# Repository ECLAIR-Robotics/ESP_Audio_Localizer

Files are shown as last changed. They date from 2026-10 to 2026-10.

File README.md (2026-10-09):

# Audio Localization
## The Basics
## The Math
# Build Guide
## Hardware
### Parts to Buy:
- ESP32 (-S3 Preferred)
- Electret Microphone
- Wiring
- M3x18 Screws
- M3 Nuts
- 3mm Magnets
### Parts to Print
- Left Body x1
- Right Body x1
- ESP Mount x1
- Mic Holder x4
## Microcontroller Code
### Structure
### Notable Constants
## Tuning the Constants
## Output
### Visualizer
### Other

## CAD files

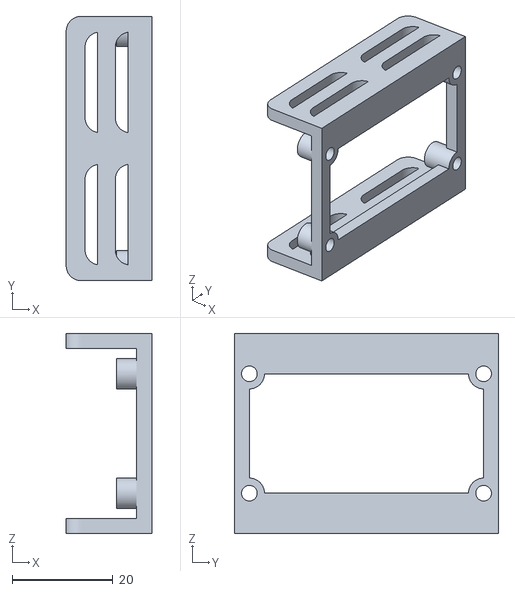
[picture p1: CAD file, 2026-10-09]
Hardware/ESP_Mount.stl
17.0 x 52.5 x 39.7

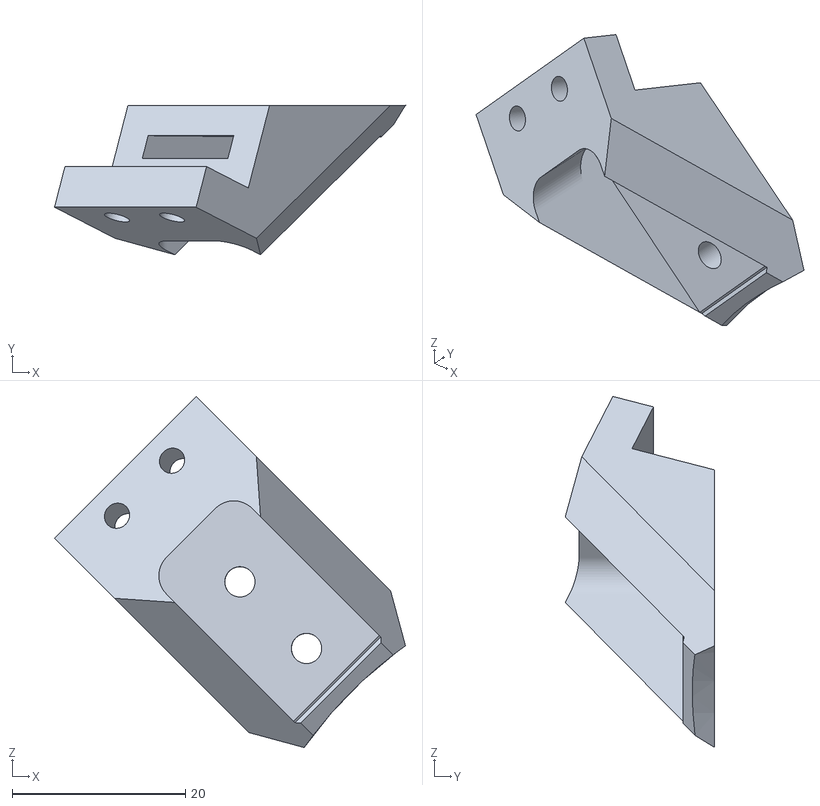
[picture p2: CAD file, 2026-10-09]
Hardware/Mic_Holder.stl
40.6 x 17.3 x 40.6

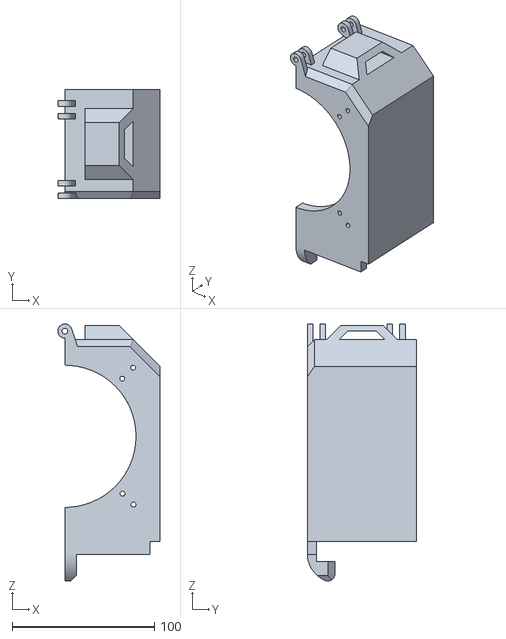
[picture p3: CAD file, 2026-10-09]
Hardware/Right_Body.stl
72.0 x 77.0 x 180.8

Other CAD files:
Hardware/Left_Body.stl

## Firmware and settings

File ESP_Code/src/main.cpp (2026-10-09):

#include <Arduino.h>
#include <WiFi.h>
#include "driver/adc.h"
#include "driver/i2s.h"
#include "soc/syscon_reg.h"
#include "soc/syscon_struct.h"
#include "soc/sens_reg.h"
#include "soc/sens_struct.h"
#include "LinAlg.h"

// ── Mode selection ────────────────────────────────────────────────────────────
// MODE_TEST      → outputs "v0,v1,v2,v3\n" (raw ADC counts) for mic_calibration.py
// MODE_PRODUCTION → outputs "az_degrees\n" (0–360) for visualizer.py
#define MODE_PRODUCTION 0
#define MODE_TEST       1
#define MODE_ROS        2
#define MODE            MODE_PRODUCTION

#define CROWDED_AREA    1   // 1 = periodic background xcorr subtraction for noisy environments

// ── Tunable constants ─────────────────────────────────────────────────────────
// SAMPLES: recording window = SAMPLES / (I2S_SAMPLE_RATE/4) ms. Trade-off:
//   fewer → shorter window, less multi-speaker bleed, noisier xcorr
//   more  → better voice SNR, higher risk of capturing a second speaker mid-window
// Multi-speaker rule of thumb: keep window ≤ 15 ms (SAMPLES ≤ 300).
// Single-speaker / music: SAMPLES = 500–600 improves voice accuracy noticeably.
static constexpr int    SAMPLES         = 300;
// I2S streams all 4 channels interleaved at I2S_SAMPLE_RATE total.
// Each mic gets I2S_SAMPLE_RATE/4 = 20 kHz → 50 µs per mic-sample.
static constexpr int    I2S_SAMPLE_RATE = 80000;
static constexpr int    I2S_DMA_BUF_LEN = 256;
static constexpr int    I2S_DMA_BUF_CNT = 4;

// XCORR_RANGE: at 20 kHz/mic (80 kHz total), max TDOA across 17.7 cm diagonal ≈ 10.3 samples. Use 12.
static constexpr int    XCORR_RANGE     = 12;

// VOLTAGE: per-mic 12-bit ADC count at idle. Calibrate with MODE_TEST first.
static constexpr int    VOLTAGE[4]      = {1919, 1913, 1915, 1925};

// THRESHOLD: single-sample abs deviation that fires the recording trigger.
static constexpr int           THRESHOLD    = 50; //400
// COOLDOWN_MS: silence window after each recording — suppresses echo re-triggers.
static constexpr unsigned long COOLDOWN_MS  = 200;
#if CROWDED_AREA
// BG_UPDATE_MS: how often to re-sample the ambient background (during silence).
static constexpr unsigned long BG_UPDATE_MS = 2000;
// BG_ALPHA: EMA weight applied to each new background estimate (0=never update, 1=instant replace).
static constexpr float         BG_ALPHA     = 0.5f;
// CALIBRATION_MS: silent window used to measure ambient noise and set dynamic threshold
// (run once at startup, then re-run periodically — see RECALIBRATION_MS).
static constexpr unsigned long CALIBRATION_MS = 2000;
// CAL_SIGMA_MULT: how many std-devs above the noise mean a sample must deviate to trigger.
// Lower = more sensitive (more false triggers from noise); higher = less sensitive (misses quieter sounds).
static constexpr float         CAL_SIGMA_MULT  = 1.5f;
// CAL_FLOOR_MARGIN: minimum trigger margin above the noise mean, even if std_dev is ~0.
static constexpr int           CAL_FLOOR_MARGIN = 100;
// RECALIBRATION_MS: how often to re-run calibration after the previous one finishes,
// so the noise floor tracks a changing crowd/environment.
static constexpr unsigned long RECALIBRATION_MS = 5UL * 60 * 1000;
#endif

static constexpr double SPEED_SOUND     = 343.0;
static constexpr bool   INCL_EDGE       = false;
// NCC_THRESHOLD: minimum normalized cross-correlation peak to accept a TDOA estimate.
// Raise if random-direction readings persist; lower if real sounds are being rejected.
static constexpr float  NCC_THRESHOLD   = 0.25f;

// CH_SKEW_US: within-cycle sampling delay per channel (12.5 µs/slot at 80 kHz).
// Scan order CH0→CH3→CH6→CH7 means mic1 is sampled 12.5 µs after mic0, etc.
static constexpr double CH_SKEW_US[4]  = {0.0, 12.5, 25.0, 37.5};

// ── ADC wiring ────────────────────────────────────────────────────────────────
// GPIO 36 (VP) = ADC1_CH0  → MIC 0
// GPIO 39 (VN) = ADC1_CH3  → MIC 1
// GPIO 34      = ADC1_CH6  → MIC 2
// GPIO 35      = ADC1_CH7  → MIC 3
static const adc1_channel_t MIC_CH[4] = {
    ADC1_CHANNEL_0, ADC1_CHANNEL_3, ADC1_CHANNEL_6, ADC1_CHANNEL_7,
};
// Reverse lookup: ADC1 channel index (0–7) → mic index, -1 = unused
static const int CH_TO_MIC[8] = {0, -1, -1, 1, -1, -1, 2, 3};

// ── Microphone geometry (meters, 12.5 cm square) ─────────────────────────────
static const Vector MIC_LOC[4] = {
    { 0.0625, -0.0625, 0},
    { 0.0625,  0.0625, 0},
    {-0.0625,  0.0625, 0},
    {-0.0625, -0.0625, 0},
};
static const int MIC_PAIRS[6][2] = {{0,1},{0,2},{0,3},{1,2},{1,3},{2,3}};

// ── Sample buffers ────────────────────────────────────────────────────────────
static int          reads[4][SAMPLES];
static unsigned int ts[4][SAMPLES];       // pre-filled uniform 100 µs spacing
static int          fill[4]    = {0};
static bool         recording     = false;
static bool         align_to_ch0  = false;
static uint16_t     dma_buf[I2S_DMA_BUF_LEN];

// ── Internal types ────────────────────────────────────────────────────────────
struct AnnotatedVec {
    Vector v; bool edge;
    AnnotatedVec() : v(), edge(true) {}
    AnnotatedVec(Vector _v, bool _e) : v(_v), edge(_e) {}
};
struct Cone {
    Vector n; double s;
    Cone() : n(), s(0) {}
    Cone(Vector _n, double _s) : n(_n), s(_s) {}
};
static Cone cones[6];

#if CROWDED_AREA
static float         bg_xcorr[6][2 * XCORR_RANGE + 1]; // per-pair background xcorr (float for EMA)
static bool          bg_valid        = false;
static int           bg_buf[4][SAMPLES];
static bool          bg_capturing    = false;
static bool          bg_align_to_ch0 = false;
static int           bg_fill[4]      = {0};
static unsigned long last_bg_ms      = 0;
static bool          calibrating      = true;
static long long     cal_sum          = 0;
static long long     cal_sum2         = 0;   // sum of squares for 3-sigma threshold
static long          cal_count        = 0;
static int           dynamic_threshold = THRESHOLD;
static unsigned long calibration_start_ms = 0;
static unsigned long last_calibration_end_ms = 0; // used to schedule the next recalibration
#endif

// ── Cross-correlation TDOA ────────────────────────────────────────────────────
// Returns time offset in seconds. Negative = a received the signal first.
static double xcorr_tdoa(const int* a, const unsigned int* a_ts, int va,
                          const int* b, const unsigned int* b_ts, int vb,
                          const float* bg_sub = nullptr) {
    double time_step = 1e-6 * (((long)a_ts[SAMPLES-1] - a_ts[0]) +
                                ((long)b_ts[SAMPLES-1] - b_ts[0])) / (2.0 * (SAMPLES - 1));

    static long xcorr[2 * XCORR_RANGE + 1];
    for (int lag = -XCORR_RANGE; lag <= XCORR_RANGE; lag++) {
        long corr = 0;
        int  lo2  = (lag >= 0) ? lag + 1 : 1;   // keeps a[i-1] and b[i-lag-1] in bounds
        int  hi2  = (lag >= 0) ? SAMPLES : SAMPLES + lag;
        for (int i = lo2; i < hi2; i++)
            corr += (int32_t)(a[i] - a[i-1]) * (int32_t)(b[i-lag] - b[i-lag-1]);
        xcorr[lag + XCORR_RANGE] = corr;
    }

    // Optionally subtract background xcorr (CROWDED_AREA); convert to float for peak detection.
    float xcorr_f[2 * XCORR_RANGE + 1];
    for (int i = 0; i <= 2 * XCORR_RANGE; i++)
        xcorr_f[i] = bg_sub ? (float)xcorr[i] - bg_sub[i] : (float)xcorr[i];

    int pk = 0;
    for (int i = 1; i <= 2 * XCORR_RANGE; i++)
        if (xcorr_f[i] > xcorr_f[pk]) pk = i;

    // NCC quality gate: peak must be large relative to both signal energies.
    // Filters noisy-but-positive peaks that give wrong TDOA on low-SNR recordings.
    {
        float ea = 0.0f, eb = 0.0f;
        for (int i = 1; i < SAMPLES; i++) {
            float da = (float)(a[i] - a[i-1]), db = (float)(b[i] - b[i-1]);
            ea += da*da; eb += db*db;
        }
        if (ea < 1.0f || eb < 1.0f ||
            xcorr_f[pk] / (sqrtf(ea) * sqrtf(eb)) < NCC_THRESHOLD)
            return NAN;
    }

    double interp = pk;
    if (pk > 0 && pk < 2 * XCORR_RANGE) {
        double fa = xcorr_f[pk-1], fb = xcorr_f[pk], fc = xcorr_f[pk+1];
        double denom = fa - 2.0*fb + fc;
        if (fabs(denom) > 1.0)
            interp = pk + 0.5*(fa - fc) / denom;
    }

    return time_step * (interp - XCORR_RANGE);
}

#if CROWDED_AREA
// Computes first-diff xcorr for all 6 pairs from bg_buf[] and EMA-blends into bg_xcorr[].
static void update_bg_xcorr() {
    for (int pi = 0; pi < 6; pi++) {
        const int a = MIC_PAIRS[pi][0], b = MIC_PAIRS[pi][1];
        for (int lag = -XCORR_RANGE; lag <= XCORR_RANGE; lag++) {
            long corr = 0;
            const int lo2 = (lag >= 0) ? lag + 1 : 1;
            const int hi2 = (lag >= 0) ? SAMPLES : SAMPLES + lag;
            for (int i = lo2; i < hi2; i++)
                corr += (int32_t)(bg_buf[a][i] - bg_buf[a][i-1])
                      * (int32_t)(bg_buf[b][i-lag] - bg_buf[b][i-lag-1]);
            const int idx = lag + XCORR_RANGE;
            bg_xcorr[pi][idx] = bg_valid
                ? BG_ALPHA * (float)corr + (1.0f - BG_ALPHA) * bg_xcorr[pi][idx]
                : (float)corr;
        }
    }
    bg_valid     = true;
    last_bg_ms   = millis();
    bg_capturing = false;
    Serial.println("bg");   // diagnostic: remove once verified
}
#endif

// ── Cone geometry ─────────────────────────────────────────────────────────────
static inline int sign_of(double x) { return (x > 0) - (x < 0); }

// Returns the tangent of the cone's half-angle (slope = adjacent/opposite).
// Returns 0 if dt is effectively zero (source equidistant → skip this pair).
static double cone_slope(double dt, double dist) {
    if (fabs(dt) < 1e-9) return 0.0;   // guard: avoids sqrt(dist²)/0
    double ct = SPEED_SOUND * fabs(dt);
    return (dist <= ct) ? 0.0 : sqrt(dist*dist - ct*ct) / ct;
}

static AnnotatedVec cone_intersect(const Cone& c1, const Cone& c2) {
    double alpha = atan(c1.s);
    double beta  = atan(c2.s);
    double theta = acos(fmax(-1.0, fmin(1.0, dot(c1.n, c2.n))));
    Vector ax    = normalize(cross(c2.n, c1.n));
    double z     = cos(alpha);
    double bz1   = cos(theta - beta);
    double bz2   = cos(theta + beta);

    if ((bz1 > z) == (bz2 > z)) {
        double diffs[4] = {
            fabs((theta-beta) - alpha), fabs((theta+beta) - alpha),
            fabs((theta-beta) + alpha), fabs((theta+beta) + alpha),
        };
        int mi = 0;
        for (int i = 1; i < 4; i++) if (diffs[i] < diffs[mi]) mi = i;
        double ang = (mi == 0) ?  beta + ((theta-beta)-alpha)/2.0
                   : (mi == 1) ? -beta + ((theta+beta)-alpha)/2.0
                   : (mi == 2) ?  beta + ((theta-beta)+alpha)/2.0
                   :             -beta + ((theta+beta)+alpha)/2.0;
        return AnnotatedVec(matrix_multiplication(rotaion_matrix_around_axis(ax, -ang), c2.n), true);
    }

    Vector w     = Vector(0, sin(theta - beta), cos(theta - beta));
    Vector nv    = Vector(0, sin(theta),        cos(theta));
    double denom = w.z - w.y*nv.y*nv.z - nv.z*nv.z*w.z;
    if (fabs(denom) < 1e-9) return AnnotatedVec();
    double ang   = acos(fmax(-1.0, fmin(1.0, (z - w.y*nv.y*nv.z - nv.z*nv.z*w.z) / denom)));
    Vector base  = matrix_multiplication(rotaion_matrix_around_axis(ax, beta), c2.n);
    Vector d1    = matrix_multiplication(rotaion_matrix_around_axis(c2.n,  ang), base);
    Vector d2    = matrix_multiplication(rotaion_matrix_around_axis(c2.n, -ang), base);
    return AnnotatedVec(d1.z > 0 ? d1 : d2, false);
}

static Vector sound_direction() {
    for (int i = 0; i < 6; i++) {
        int a = MIC_PAIRS[i][0], b = MIC_PAIRS[i][1];
        double dt = xcorr_tdoa(reads[a], ts[a], VOLTAGE[a], reads[b], ts[b], VOLTAGE[b],
#if CROWDED_AREA
                               bg_valid ? bg_xcorr[i] : nullptr
#else
                               nullptr
#endif
                               );
        dt -= (CH_SKEW_US[b] - CH_SKEW_US[a]) * 1e-6;
        if (isnan(dt))                              { cones[i] = Cone(); continue; } // uncorrelated
        if (fabs(dt) < 1e-9)                        { cones[i] = Cone(); continue; } // equidistant
        double dist = magnitude(MIC_LOC[b] - MIC_LOC[a]);
        if (SPEED_SOUND * fabs(dt) >= dist)         { cones[i] = Cone(); continue; } // impossible TDOA
        cones[i] = Cone(normalize(MIC_LOC[b] - MIC_LOC[a]) * sign_of(dt),
                        cone_slope(dt, dist));
    }

    // Sum valid cone normals → guide vector pointing toward the source hemisphere.
    // Each cone normal already points toward the closer mic (= source side), so
    // the sum is a stable, geometry-free reference for resolving the 180° ambiguity.
    Vector guide(0, 0, 0);
    for (int i = 0; i < 6; i++)
        if (magnitude(cones[i].n) > 0.5) guide = guide + cones[i].n;

#if CROWDED_AREA
    {
        int valid = 0;
        for (int i = 0; i < 6; i++)
            if (magnitude(cones[i].n) > 0.5) valid++;
        if (valid < 3) return Vector(0, 0, 0);
    }
#endif

    Vector candidates[13];
    int n = 0;
    for (int i = 0; i < 5; i++) {
        for (int j = i + 1; j < 6; j++) {
            if ((i == 0 && j == 5) || (i == 1 && j == 4)) continue; // co-axial pairs
            if (magnitude(cones[i].n) < 0.5 || magnitude(cones[j].n) < 0.5) continue;
            if (dot(cones[i].n, cones[j].n) > 0.94) continue; // < 20° apart → ill-conditioned
            AnnotatedVec av = cone_intersect(cones[i], cones[j]);
            if (!av.edge || INCL_EDGE) candidates[n++] = av.v;
        }
    }

    if (n == 0) return Vector(0, 0, 1);

    // Single-pass consensus: flip any candidate pointing against the guide, then sum.
    // Faster than the old two-pass and more reliable because the guide is derived
    // directly from which mic received first rather than from the candidates themselves.
    Vector sum(0, 0, 0);
    for (int i = 0; i < n; i++) {
        Vector v = candidates[i];
        if (dot(v, guide) < 0.0) v = v * -1;
        sum = sum + v;
    }

    return normalize(sum);
}

// ── Arduino entry points ──────────────────────────────────────────────────────
void setup() {
    Serial.begin(115200);
    WiFi.mode(WIFI_OFF);

    for (int i = 0; i < 4; i++)
        adc1_config_channel_atten(MIC_CH[i], ADC_ATTEN_DB_11);

    // Pre-fill ts with uniform 100 µs spacing (10 kHz per mic at 40 kHz total)
    const unsigned int PERIOD_US = 4 * 1000000UL / I2S_SAMPLE_RATE; // = 100
    for (int j = 0; j < SAMPLES; j++)
        for (int i = 0; i < 4; i++)
            ts[i][j] = j * PERIOD_US;

    const i2s_config_t i2s_cfg = {
        .mode                 = (i2s_mode_t)(I2S_MODE_MASTER | I2S_MODE_RX | I2S_MODE_ADC_BUILT_IN),
        .sample_rate          = I2S_SAMPLE_RATE,
        .bits_per_sample      = I2S_BITS_PER_SAMPLE_16BIT,
        .channel_format       = I2S_CHANNEL_FMT_ONLY_RIGHT,
        .communication_format = I2S_COMM_FORMAT_I2S_MSB,
        .intr_alloc_flags     = ESP_INTR_FLAG_LEVEL1,
        .dma_buf_count        = I2S_DMA_BUF_CNT,
        .dma_buf_len          = I2S_DMA_BUF_LEN,
        .use_apll             = false,
        .tx_desc_auto_clear   = false,
        .fixed_mclk           = 0,
    };
    i2s_driver_install(I2S_NUM_0, &i2s_cfg, 0, NULL);
    i2s_set_adc_mode(ADC_UNIT_1, MIC_CH[0]);

    // Enable all 4 pads BEFORE i2s_adc_enable
    SENS.sar_meas_start1.sar1_en_pad = (1<<0)|(1<<3)|(1<<6)|(1<<7);

    i2s_adc_enable(I2S_NUM_0);

    // i2s_adc_enable resets PATT_LEN to 0. Overwrite the scan pattern AFTER enable.
    // Entry format: [7:4]=channel, [3:2]=bit_width (3=12-bit), [1:0]=atten (3=11dB)
    SYSCON.saradc_ctrl.sar1_patt_len = 3; // 4 entries (len = count - 1)
    SYSCON.saradc_sar1_patt_tab[0] =
        ((uint32_t)((0<<4)|(3<<2)|3) << 24) |  // CH0 = mic0
        ((uint32_t)((3<<4)|(3<<2)|3) << 16) |  // CH3 = mic1
        ((uint32_t)((6<<4)|(3<<2)|3) <<  8) |  // CH6 = mic2
        ((uint32_t)((7<<4)|(3<<2)|3) <<  0);   // CH7 = mic3
    SYSCON.saradc_ctrl.sar1_patt_p_clear = 1;
    SYSCON.saradc_ctrl.sar1_patt_p_clear = 0;

#if CROWDED_AREA
    calibration_start_ms = millis();
    Serial.println("calibrating...");
#else
    Serial.println("ready");
#endif
}

#if MODE == MODE_TEST
// ── Test loop: outputs "v0,v1,v2,v3\n" per DMA buffer for mic_calibration.py ─
void loop() {
    size_t bytes_read;
    i2s_read(I2S_NUM_0, dma_buf, sizeof(dma_buf), &bytes_read, portMAX_DELAY);
    const int n = (int)(bytes_read / 2);

    int latest[4] = {-1, -1, -1, -1};
    for (int s = 0; s < n; s++) {
        const uint16_t raw = dma_buf[s];
        const int ch = (raw >> 12) & 0xF;
        if (ch > 7) continue;
        const int m = CH_TO_MIC[ch];
        if (m < 0) continue;
        latest[m] = (int)(raw & 0xFFF);
    }
    if (latest[0] < 0 || latest[1] < 0 || latest[2] < 0 || latest[3] < 0) return;
    Serial.printf("%d,%d,%d,%d\n", latest[0], latest[1], latest[2], latest[3]);
}

#else
// ── Production loop: outputs "az_degrees\n" (0–360) for visualizer.py ────────
void loop() {
    static unsigned long last_output_ms = 0;
    size_t bytes_read;
    i2s_read(I2S_NUM_0, dma_buf, sizeof(dma_buf), &bytes_read, portMAX_DELAY);
    const int n = (int)(bytes_read / 2);

    for (int s = 0; s < n; s++) {
        const uint16_t raw = dma_buf[s];
        const int ch = (raw >> 12) & 0xF;
        if (ch > 7) continue;
        const int m = CH_TO_MIC[ch];
        if (m < 0) continue;
        const int val = (int)(raw & 0xFFF);

        if (!recording) {
#if CROWDED_AREA
            if (calibrating) {
                long dev = abs(val - VOLTAGE[m]);
                cal_sum  += dev;
                cal_sum2 += dev * dev;
                cal_count++;
                if (millis() - calibration_start_ms > CALIBRATION_MS) {
                    if (cal_count > 0) {
                        int avg     = (int)(cal_sum / cal_count);
                        float var   = (float)(cal_sum2 / cal_count) - (float)avg * (float)avg;
                        int std_dev = (int)sqrtf(var > 0.0f ? var : 0.0f);
                        dynamic_threshold = avg + (int)(CAL_SIGMA_MULT * std_dev);
                        if (dynamic_threshold < avg + CAL_FLOOR_MARGIN) dynamic_threshold = avg + CAL_FLOOR_MARGIN;
                        Serial.printf("ready: avg=%d std=%d threshold=%d\n", avg, std_dev, dynamic_threshold);
                    } else {
                        dynamic_threshold = THRESHOLD;
                        Serial.printf("ready: threshold=%d\n", dynamic_threshold);
                    }
                    calibrating          = false;
                    last_calibration_end_ms = millis();
                }
            } else {
                const bool trigger = abs(val - VOLTAGE[m]) > dynamic_threshold
                                     && millis() - last_output_ms > COOLDOWN_MS;
                if (trigger) {
                    bg_capturing     = false;
                    recording        = true;
                    align_to_ch0     = true;
                    for (int i = 0; i < 4; i++) fill[i] = 0;
                } else if (bg_capturing) {
                    if (bg_align_to_ch0) {
                        if (m == 0) bg_align_to_ch0 = false; else { continue; }
                    }
                    if (bg_fill[m] < SAMPLES) bg_buf[m][bg_fill[m]++] = val;
                } else if (millis() - last_calibration_end_ms > RECALIBRATION_MS
                           && millis() - last_output_ms > COOLDOWN_MS) {
                    calibrating          = true;
                    calibration_start_ms = millis();
                    cal_sum = cal_sum2 = 0;
                    cal_count            = 0;
                    Serial.println("recalibrating...");
                } else if (millis() - last_bg_ms > BG_UPDATE_MS
                           && millis() - last_output_ms > COOLDOWN_MS) {
                    bg_capturing    = true;
                    bg_align_to_ch0 = true;
                    for (int i = 0; i < 4; i++) bg_fill[i] = 0;
                }
            }
#else
            const bool trigger = abs(val - VOLTAGE[m]) > THRESHOLD
                                 && millis() - last_output_ms > COOLDOWN_MS;
            if (trigger) {
                recording    = true;
                align_to_ch0 = true;
                for (int i = 0; i < 4; i++) fill[i] = 0;
            }
#endif
            continue;
        }

        // Skip samples until the next CH0 so all mics start at the same scan position
        if (align_to_ch0) {
            if (m == 0) align_to_ch0 = false;
            else continue;
        }

        if (fill[m] < SAMPLES)
            reads[m][fill[m]++] = val;
    }

#if CROWDED_AREA
    if (bg_capturing) {
        bool done = true;
        for (int i = 0; i < 4; i++) if (bg_fill[i] < SAMPLES) { done = false; break; }
        if (done) update_bg_xcorr();
    }
#endif

    if (!recording) return;
    for (int i = 0; i < 4; i++) if (fill[i] < SAMPLES) return;

    recording = false;
    last_output_ms = millis();
    Vector dir = sound_direction();
    if (magnitude(dir) < 0.5) return;   // CROWDED_AREA: too few valid cone pairs
#if MODE == MODE_ROS
    Serial.printf("Vector(%.4f,%.4f,%.4f)\n", dir.x, dir.y, dir.z);
#else
    double az  = atan2(dir.y, dir.x) * 180.0 / M_PI;
    if (az < 0.0) az += 360.0;   // convert (-180,180] → [0,360)
    Serial.printf("%.1f\n", az);
#endif
}
#endif

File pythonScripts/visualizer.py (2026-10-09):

"""
Sound localizer visualizer.
Reads angle values (0-360) from the ESP32 over serial and draws a live direction line.

Requirements:
    pip install pyserial matplotlib numpy
"""

import sys
import queue
import threading
from collections import deque

import numpy as np
import matplotlib.pyplot as plt
import matplotlib.animation as animation
import serial
import serial.tools.list_ports

# ── Config ────────────────────────────────────────────────────────────────────
BAUD_RATE   = 115200
PORT        = 'COM3'      # fallback if auto-detect finds nothing
TRAIL_LEN   = 8           # number of ghost lines shown behind the current reading
UPDATE_MS   = 50          # plot refresh interval in milliseconds

DISPLAY_ROTATION_DEG = 90  # rotate the whole compass display clockwise ("to the right")

def rotate_xy(x, y, deg=DISPLAY_ROTATION_DEG):
    """Rotate a cartesian point clockwise by deg."""
    rad = np.radians(deg)
    c, s = np.cos(rad), np.sin(rad)
    return x * c + y * s, -x * s + y * c

def dir_xy(deg, r=1.0):
    """Unit vector (scaled by r) for a compass angle, with display rotation applied."""
    rad = np.radians(deg - DISPLAY_ROTATION_DEG)
    return r * np.cos(rad), r * np.sin(rad)

# Mic positions in metres — must match MIC_LOC order in main.cpp
MIC_POS = np.array([
    [ 0.0625, -0.0625],   # MIC 1  VP  (GPIO 36)
    [ 0.0625,  0.0625],   # MIC 2  VN  (GPIO 39)
    [-0.0625,  0.0625],   # MIC 3      (GPIO 34)
    [-0.0625, -0.0625],   # MIC 4      (GPIO 35)
])
MIC_POS = np.array([rotate_xy(x, y) for x, y in MIC_POS])
MIC_LABELS = ['1 (VP)', '2 (VN)', '3 (34)', '4 (35)']

# ── Serial reader (background thread) ────────────────────────────────────────
angle_queue: queue.Queue = queue.Queue()

def find_port() -> str:
    for p in serial.tools.list_ports.comports():
        if any(k in p.description.upper() for k in ('CP210', 'CH340', 'USB', 'ESP')):
            return p.device
    ports = serial.tools.list_ports.comports()
    return ports[0].device if ports else PORT

def serial_thread(port: str) -> None:
    try:
        ser = serial.Serial(port, BAUD_RATE, timeout=1)
        print(f"Connected on {port} at {BAUD_RATE} baud")
    except serial.SerialException as e:
        print(f"Could not open {port}: {e}")
        sys.exit(1)

    while True:
        try:
            raw = ser.readline().decode('utf-8', errors='ignore').strip()
            val = float(raw)
            if 0.0 <= val <= 360.0:
                angle_queue.put(val)
        except (ValueError, UnicodeDecodeError):
            pass

# ── Plot setup ────────────────────────────────────────────────────────────────
plt.style.use('dark_background')
fig, ax = plt.subplots(figsize=(7, 7))
ax.set_aspect('equal')
ax.axis('off')
ax.set_title('Sound Localizer', fontsize=16, pad=12, color='white')

PLOT_R = 0.145
ax.set_xlim(-PLOT_R, PLOT_R)
ax.set_ylim(-PLOT_R, PLOT_R)

# Compass rings
for r, alpha in [(0.055, 0.25), (0.11, 0.35)]:
    ax.add_patch(plt.Circle((0, 0), r, fill=False, color='white', alpha=alpha, lw=1))

# Cardinal tick marks and labels
for deg in range(0, 360, 30):
    inner, outer = 0.108, 0.118
    ax.plot([dir_xy(deg, inner)[0], dir_xy(deg, outer)[0]],
            [dir_xy(deg, inner)[1], dir_xy(deg, outer)[1]],
            color='white', alpha=0.4, lw=1)
for deg, label in [(0,'0°'), (90,'90°'), (180,'180°'), (270,'270°')]:
    ax.text(*dir_xy(deg, 0.135), label,
            ha='center', va='center', fontsize=9, color='gray')

# Microphone squares
for pos, label in zip(MIC_POS, MIC_LABELS):
    ax.plot(*pos, 's', color='#4FC3F7', markersize=13, zorder=5)
    nudge = pos / np.linalg.norm(pos) * 0.024
    ax.text(*(pos + nudge), label, ha='center', va='center',
            fontsize=8, color='#4FC3F7', zorder=6)

# Centre dot
ax.plot(0, 0, 'o', color='white', markersize=5, zorder=6)

# Direction line — one active + TRAIL_LEN ghosts
LINE_LEN   = 0.10
TRAIL_COLOR = '#FF5252'

trail_lines = []
for i in range(TRAIL_LEN):
    alpha = 0.08 + 0.12 * (i / TRAIL_LEN)
    ln, = ax.plot([], [], '-', color=TRAIL_COLOR, lw=1.5, alpha=alpha, zorder=3)
    trail_lines.append(ln)

active_line, = ax.plot([], [], '-',  color=TRAIL_COLOR, lw=2.5, zorder=4)
active_tip,  = ax.plot([], [], '^',  color=TRAIL_COLOR, markersize=11, zorder=4)

angle_text = ax.text(0, -PLOT_R + 0.005, '—', ha='center', va='bottom',
                     fontsize=22, fontweight='bold', color='white')

# ── Animation ─────────────────────────────────────────────────────────────────
history: deque = deque(maxlen=TRAIL_LEN + 1)

def update(_):
    while not angle_queue.empty():
        history.append(angle_queue.get())

    if not history:
        return [active_line, active_tip, angle_text] + trail_lines

    # Current reading
    dx, dy = dir_xy(history[-1], LINE_LEN)
    active_line.set_data([0, dx], [0, dy])
    active_tip.set_data([dx], [dy])
    angle_text.set_text(f'{history[-1]:.1f}°')

    # Ghost trail (oldest = most faded)
    past = list(history)[:-1]
    for i, ln in enumerate(trail_lines):
        if i < len(past):
            dx2, dy2 = dir_xy(past[i], LINE_LEN)
            ln.set_data([0, dx2], [0, dy2])
        else:
            ln.set_data([], [])

    return [active_line, active_tip, angle_text] + trail_lines

# ── Entry point ───────────────────────────────────────────────────────────────
if __name__ == '__main__':
    port = sys.argv[1] if len(sys.argv) > 1 else find_port()
    threading.Thread(target=serial_thread, args=(port,), daemon=True).start()
    ani = animation.FuncAnimation(fig, update, interval=UPDATE_MS, blit=True)
    plt.tight_layout()
    plt.show()

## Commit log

2026-10-09 added hardware
    [ESP_Mount.stl, Left_Body.stl, Mic_Holder.stl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]
2026-10-09 Add 'Parts to Print' section in README
    Added a new section for parts to print in the README.
